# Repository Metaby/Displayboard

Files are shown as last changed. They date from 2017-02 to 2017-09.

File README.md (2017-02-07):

# Displayboard
This is the repository for my free time project. I developed the circuits to drive an DOGXL display with touchpanel from Electronic Assembly. It is driven by two Atmel microcontrollers. One ATtiny for the Touchpanel multiplexing and reading and one ATmega for driving the display itself (simple operating system, graphics driver).
The project is split into three parts
- Circuits, EAGLE files for the circuit board
- TPU, The touchpanel driver/firmware for the ATtiny
- GPU, The display driver/firmware (including a simple operating system) for the ATmega

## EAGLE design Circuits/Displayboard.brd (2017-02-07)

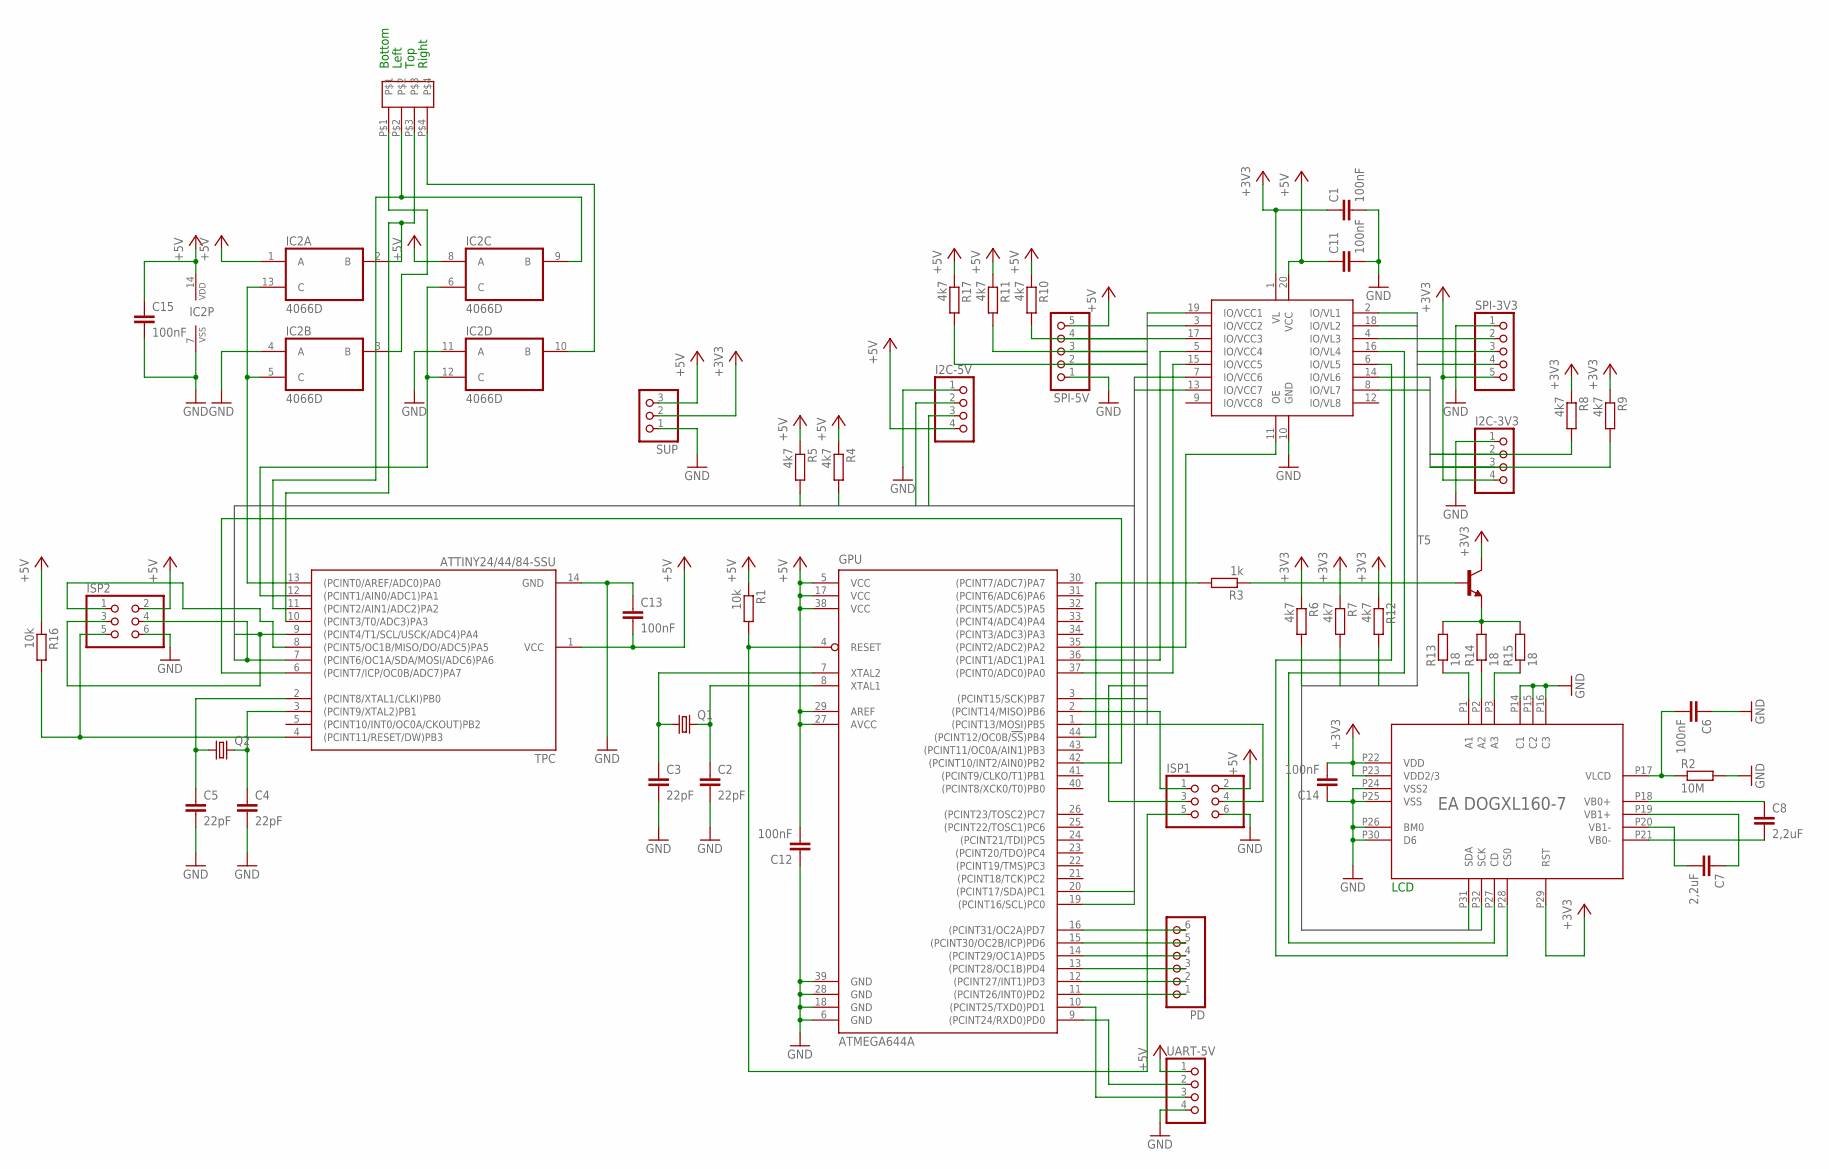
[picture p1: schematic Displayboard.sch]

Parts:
C1, C6, C11, C12, C13, C14, C15: 100nF; C1206
C2, C3, C4, C5: 22pF; C1206
C7, C8: 2,2uF; C1206
EADOGXL160-7: DOGXL
GPU: ATMEGA644A; TQFP44
I2C-3V3, I2C-5V: PINHD-1X4/90; 1X04/90
IC1: ST2378; TSSOP-20
IC2: 4066D; SO14
ISP1, ISP2: PINHD-2X3/90; 2X03/90
PD: PINHD-1X6/90; 1X06/90
Q1, Q2: CRYSTALHC49UP; HC49UP
R1, R16: 10k; R1206
R2: 10M; R1206
R3: 1k; R1206
R4, R5, R6, R7, R8, R9, R10, R11, R12, R17: 4k7; R1206
R13, R14, R15: 18; R1206
SPI-3V3, SPI-5V: PINHD-1X5/90; 1X05/90
SUP: PINHD-1X3/90; 1X03/90
T5: BCX19-NPN-SOT23-BEC; SOT23-BEC
TPC: ATTINY24/44/84-SSU; SOIC14
U$1: ZIF-4-1
UART-5V: PINHD-1X4/90; 1X04/90

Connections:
+3V3: C1.1, C14.2, EADOGXL160-7.P22 (VDD), EADOGXL160-7.P23 (VDD2/3), EADOGXL160-7.P29 (RST), I2C-3V3.4, IC1.1 (VL), R6.1, R7.1, R8.1, R9.1, R12.1, SPI-3V3.5, SUP.2, T5.C
+5V: C11.1, C12.2, C13.2, C15.1, GPU.5 (VCC), GPU.17 (VCC), GPU.27 (AVCC), GPU.29 (AREF), GPU.38 (VCC), I2C-5V.4, IC1.20 (VCC), IC2.1 (A), IC2.8 (A), IC2.14 (VDD), ISP1.2, ISP2.2, R1.1, R4.1, R5.1, R10.1, R11.1, R16.1, R17.1, SPI-5V.5, SUP.3, TPC.1 (VCC), UART-5V.1
GND: C1.2, C2.2, C3.2, C4.2, C5.2, C6.1, C11.2, C12.1, C13.1, C14.1, C15.2, EADOGXL160-7.P14 (C1), EADOGXL160-7.P15 (C2), EADOGXL160-7.P16 (C3), EADOGXL160-7.P24 (VSS2), EADOGXL160-7.P25 (VSS), EADOGXL160-7.P26 (BM0), EADOGXL160-7.P30 (D6), GPU.6 (GND), GPU.18 (GND), GPU.28 (GND), GPU.39 (GND), I2C-3V3.1, I2C-5V.1, IC1.10 (GND), IC2.4 (A), IC2.7 (VSS), IC2.11 (A), ISP1.6, ISP2.6, R2.2, SPI-3V3.1, SPI-5V.1, SUP.1, TPC.14 (GND), UART-5V.4
MISO: GPU.2 ((PCINT14/MISO)PB6), IC1.3 (IO/VCC2), ISP1.1, R10.2, SPI-5V.4
MISO3: IC1.18 (IO/VL2), R6.2, SPI-3V3.4
MOSI: GPU.1 ((PCINT13/MOSI)PB5), IC1.17 (IO/VCC3), ISP1.4, R11.2, SPI-5V.3
MOSI3: EADOGXL160-7.P31 (SDA), IC1.4 (IO/VL3), R7.2, SPI-3V3.3
unnamed: C3.1, GPU.7 (XTAL2), Q1.1
unnamed: C2.1, GPU.8 (XTAL1), Q1.2
unnamed: GPU.4 (RESET), ISP1.5, R1.2
unnamed: C5.1, Q2.1, TPC.2 ((PCINT8/XTAL1/CLKI)PB0)
unnamed: C4.1, Q2.2, TPC.3 ((PCINT9/XTAL2)PB1)
unnamed: C6.2, EADOGXL160-7.P17 (VLCD), R2.1
unnamed: IC2.2 (B), TPC.10 ((PCINT3/T0/ADC3)PA3), U$1.P$3
unnamed: C8.1, EADOGXL160-7.P18 (VB0+)
unnamed: C7.1, EADOGXL160-7.P19 (VB1+)
unnamed: C7.2, EADOGXL160-7.P20 (VB1-)
unnamed: C8.2, EADOGXL160-7.P21 (VB0-)
unnamed: GPU.36 ((PCINT1/ADC1)PA1), IC1.5 (IO/VCC4)
unnamed: IC2.9 (B), TPC.11 ((PCINT2/AIN1/ADC2)PA2), U$1.P$2
unnamed: IC2.3 (B), U$1.P$1
unnamed: GPU.16 ((PCINT31/OC2A)PD7), PD.6
unnamed: IC2.5 (C), IC2.13 (C), TPC.13 ((PCINT0/AREF/ADC0)PA0)
unnamed: IC2.6 (C), IC2.12 (C), TPC.12 ((PCINT1/AIN0/ADC1)PA1)
unnamed: IC2.10 (B), U$1.P$4
unnamed: GPU.42 ((PCINT10/INT2/AIN0)PB2), TPC.6 ((PCINT7/ICP/OC0B/ADC7)PA7)
unnamed: GPU.15 ((PCINT30/OC2B/ICP)PD6), PD.5
unnamed: GPU.14 ((PCINT29/OC1A)PD5), PD.4
unnamed: EADOGXL160-7.P27 (CD), IC1.16 (IO/VL4)
unnamed: GPU.13 ((PCINT28/OC1B)PD4), PD.3
unnamed: EADOGXL160-7.P28 (CS0), IC1.6 (IO/VL5)
unnamed: GPU.37 ((PCINT0/ADC0)PA0), IC1.15 (IO/VCC5)
unnamed: GPU.12 ((PCINT27/INT1)PD3), PD.2
unnamed: GPU.35 ((PCINT2/ADC2)PA2), IC1.11 (OE)
unnamed: GPU.11 ((PCINT26/INT0)PD2), PD.1
unnamed: GPU.10 ((PCINT25/TXD0)PD1), UART-5V.3
unnamed: GPU.9 ((PCINT24/RXD0)PD0), UART-5V.2
unnamed: R3.1, T5.B
unnamed: EADOGXL160-7.P3 (A3), R15.1
unnamed: EADOGXL160-7.P2 (A2), R14.1
unnamed: EADOGXL160-7.P1 (A1), R13.1
unnamed: R13.2, R14.2, R15.2, T5.E
unnamed: ISP2.5, R16.2, TPC.4 ((PCINT11/RESET/DW)PB3)
unnamed: GPU.44 ((PCINT12/OC0B/!SS!)PB4), R3.2
unnamed: ISP2.1, TPC.8 ((PCINT5/OC1B/MISO/DO/ADC5)PA5)
SCK: GPU.3 ((PCINT15/SCK)PB7), IC1.19 (IO/VCC1), ISP1.3, R17.2, SPI-5V.2
SCK3: EADOGXL160-7.P32 (SCK), IC1.2 (IO/VL1), R12.2, SPI-3V3.2
SCL: GPU.19 ((PCINT16/SCL)PC0), I2C-5V.2, IC1.7 (IO/VCC6), ISP2.3, R5.2, TPC.9 ((PCINT4/T1/SCL/USCK/ADC4)PA4)
SCL3: I2C-3V3.2, IC1.14 (IO/VL6), R8.2
SDA: GPU.20 ((PCINT17/SDA)PC1), I2C-5V.3, IC1.13 (IO/VCC7), ISP2.4, R4.2, TPC.7 ((PCINT6/OC1A/SDA/MOSI/ADC6)PA6)
SDA3: I2C-3V3.3, IC1.8 (IO/VL7), R9.2

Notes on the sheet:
LCD
Bottom
Left
Top
Right

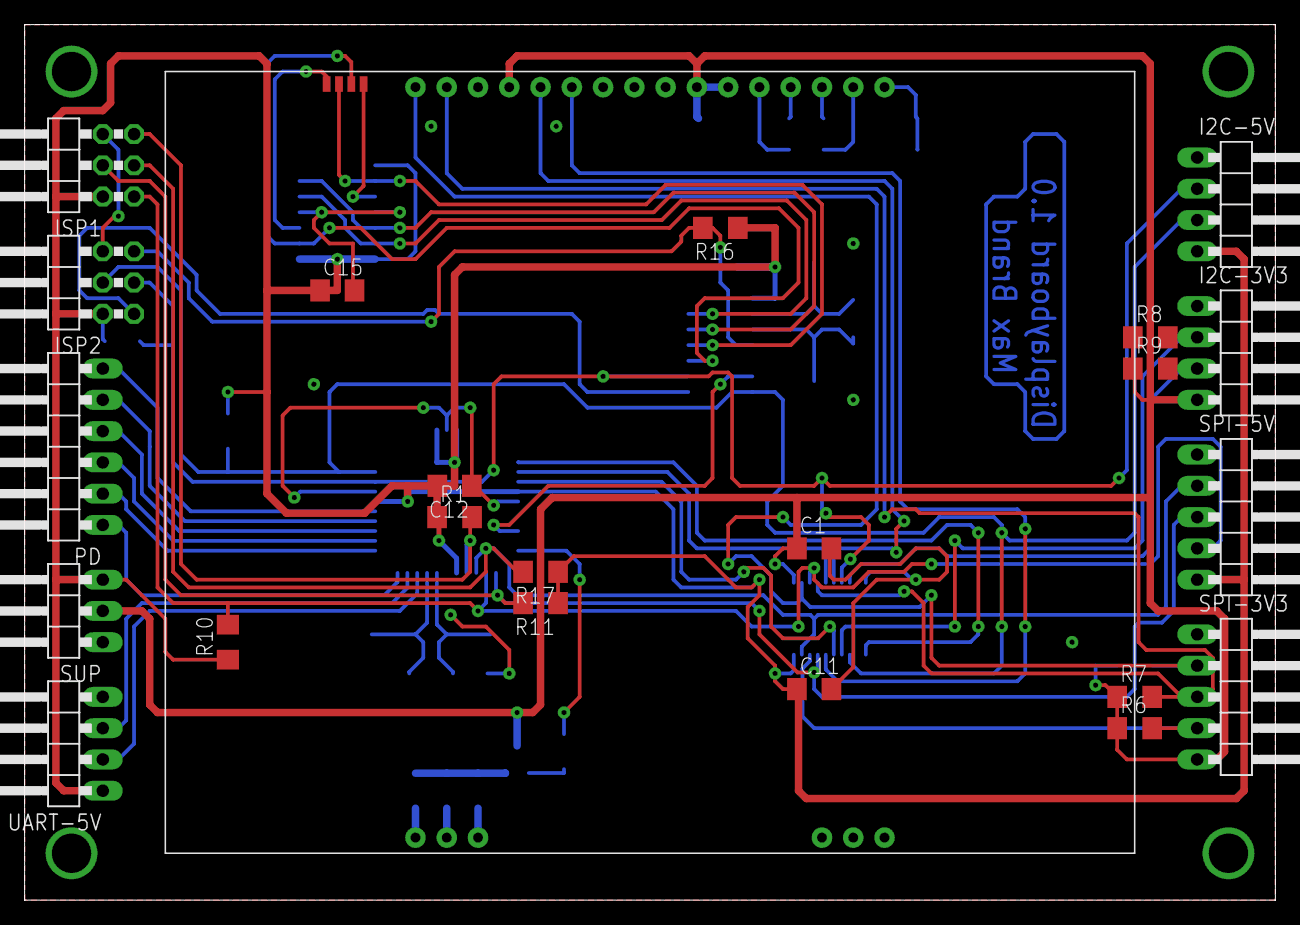
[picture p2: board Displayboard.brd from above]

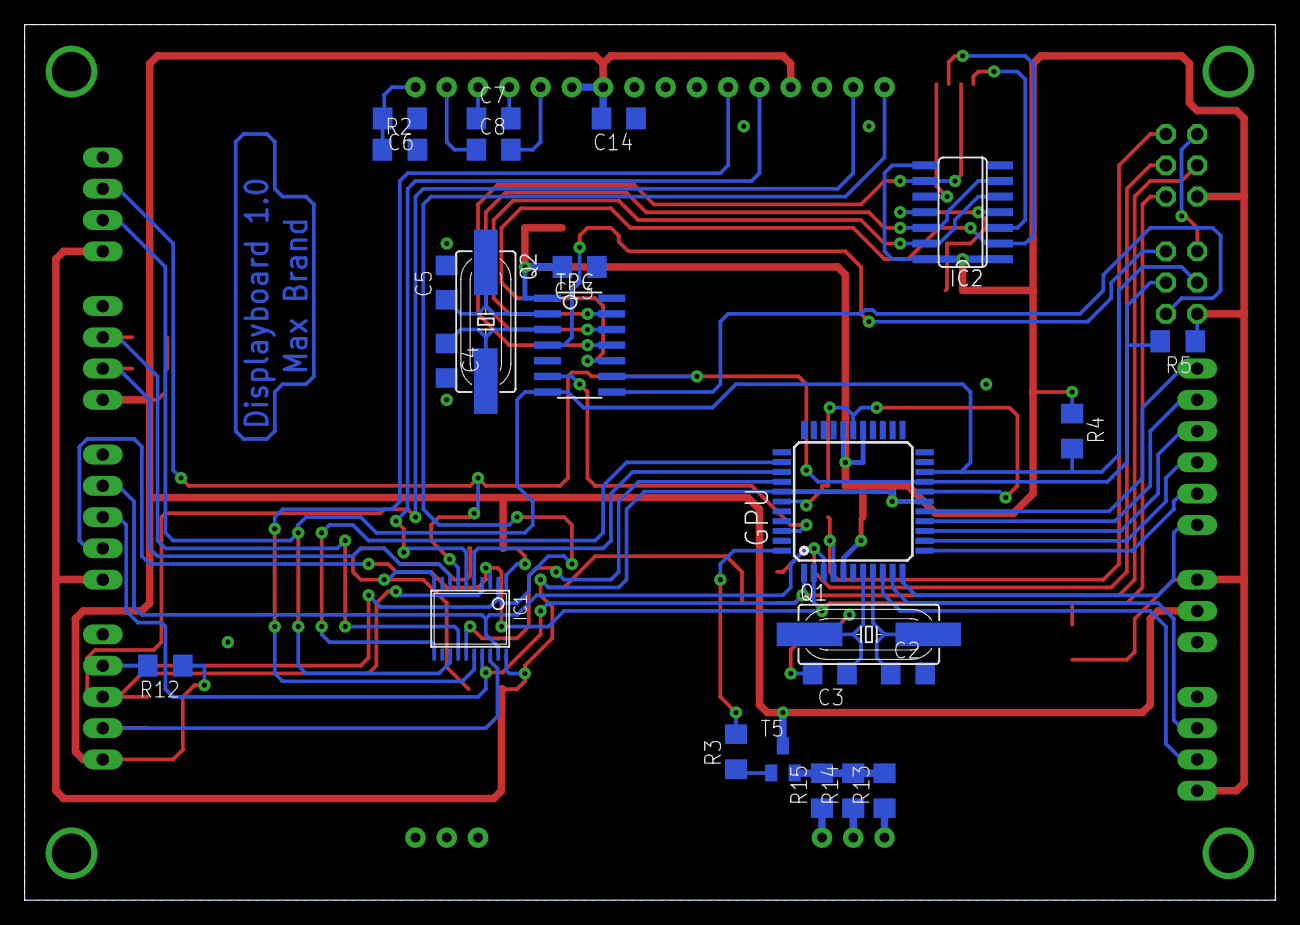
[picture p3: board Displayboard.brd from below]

Board: 2 copper layers, 101.6 x 71.1 mm, 48 parts (24 on the bottom side), 51 nets.

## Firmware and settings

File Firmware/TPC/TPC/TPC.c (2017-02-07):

/*
 * TPC.c
 *
 * Created: 09.10.2012 11:06:12
 *  Author: Max
 */
#define EnableRapidSending 0
#define F_CPU 20000000UL
#define PORTA0 0
#define PORTA1 1
#define PORTA2 2
#define PORTA3 3
#define PORTA4 4
#define PORTA5 5
#define PORTA6 6
#define PORTA7 7
#define SDA_PORT        PA6
#define SCL_PORT        PA4
#define SDA_PIN         PINA6
#define SCL_PIN         PINA4
#include <avr/io.h>
#include <util/delay.h>
#include <avr/interrupt.h>
#include "usiTwiSlave.h"

volatile uint8_t lastX = 0;
volatile uint8_t lastY = 0;

uint16_t readADC(uint8_t Channel, uint8_t Resolution)
{
	uint8_t i;
	uint32_t result = 0;
	ADCSRA = (1<<ADEN) | (1<<ADPS2) | (1<<ADPS0);
	ADMUX = Channel;
	ADCSRA |= (1<<ADSC);
	while(ADCSRA & (1<<ADSC));
	for(i=0; i < Resolution; i++) {
		ADCSRA |= (1<<ADSC);
		while(ADCSRA & (1<<ADSC));
		result += ADCW;
	}
	ADCSRA &= ~(1<<ADEN);
	result /= Resolution;
	return result;
}

void Sleep (uint16_t ms)
{
	for(; ms > 0; ms--) _delay_ms(1);
}

uint8_t SampleY()
{
	DDRA |= (1 << PORTA1) | (1 << PORTA0);
	PORTA |= (1 << PORTA0) | (1 << PORTA3);
	PORTA &= ~(1 << PORTA1);
	uint16_t minY = 400;//360;
	uint16_t maxY = 815;//815;
	return (uint8_t)((readADC(2, 10) - minY) * (104.0 / (maxY - minY)));
}

uint8_t SampleX()
{
	DDRA |= (1 << PORTA1);
	PORTA |= (1 << PORTA1) | (1 << PORTA2);
	PORTA &= ~(1 << PORTA0);
	uint16_t minX = 215;//175;
	uint16_t maxX = 830;//830;
	return (uint8_t)((readADC(3, 10) - minX) * (160.0 / (maxX - minX)));
}

void Initialize()
{
	usiTwiSlaveInit(0x0C);
	TCCR1B = (1 << CS11);
	TIMSK1 = (1 << TOIE1);
	TCNT1H = 0xAF;
	TCNT1L = 0xFF;
	Sleep(1000);
	sei();
}

int main(void)
{
	Initialize();
    while(1);
}

ISR(TIM1_OVF_vect)
{
	TIMSK1 = 0x00;
	TCNT1H = 0xAF;
	TCNT1L = 0xFF;
	uint8_t x = 160 - SampleX();
	uint8_t y = 104 - SampleY();
	uint8_t send = 0;
	if (lastX != x)
	{
		lastX = x;
		send = 1;
	}		
	if (lastY != y)
	{
		lastY = y;
		send = 1;
	}		
	txbuffer[0] = lastX;
	txbuffer[1] = lastY;
	if (send == 1 || EnableRapidSending)
	{
		DDRA |= (1 << PORTA7);
		PORTA &= ~(1 << PORTA7);
		PORTA |= (1 << PORTA7);
	}
	TIMSK1 = (1 << TOIE1);
}

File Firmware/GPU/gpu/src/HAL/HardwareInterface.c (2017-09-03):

/*
 * HardwareInterface.c
 *
 * Created: 23.11.2012 20:54:42
 *  Author: Max
 */
#include "HardwareInterface.h"

void display_initialize()
{
	DDRA = (1 << PORTA0) | (1 << PORTA1) | (1 << PORTA4);
	DDRB = (1 << PORTB4) | (1 << PORTB5) | (1 << PORTB7);
	SPCR = (1 << SPE) | (1 << MSTR);
	SPSR = (1 << SPI2X);
	display_enable(0);
	display_send_byte(0xF1);
	display_send_byte(0x67);
	display_send_byte(0xC0);
	display_send_byte(0x40);
	display_send_byte(0x50);
	display_send_byte(0x2B);
	display_send_byte(0xEB);
	display_send_byte(0x81);
	display_send_byte(0x69);
	display_send_byte(0x89);
	display_send_byte(0xAF);
	display_send_byte(0xA4);
}

void display_send_byte(uint8_t Data)
{
	SPDR = Data;
	while(!(SPSR & (1 << SPIF)));
}

void display_enable(uint8_t CD)
{
	PORTA = (0 << PORTA0) | (CD << PORTA1);
}

void display_disable()
{
	PORTA = (1 << PORTA0);
}

void display_select_column(uint8_t Column)
{
	display_enable(0);
	display_send_byte(0x0 | (Column & 0x0F));
	Column = (Column >> 4);
	display_send_byte(0x10 | (Column & 0x0F));
}

void display_select_page(uint8_t Page)
{
	display_enable(0);
	display_send_byte(0x60 | (Page & 0x1F));
}

void display_clear()
{
	display_select_column(0);
	display_select_page(0);
	display_enable(1);
	for (uint8_t i = 0; i < 200; i++)
	{
		for (uint8_t j = 0; j < 32; j++)
		{
			display_send_byte(0x00);
		}
	}
}

void display_send_buffer()
{
	display_select_column(0);
	display_select_page(0);
	display_enable(1);
	for (uint8_t y = 0; y < 26; y++)
	{
		if (display_row_flag[y] == 1)
		{
			for (uint8_t x = 0; x < 160; x++)
			{
				display_send_byte(display_buffer[x][y]);
			}
			display_row_flag[y] = 0;
		}
		else
		{
			display_enable(0);
			display_select_page(y + 1);
			display_enable(1);
		}
	}
}

void display_get_touch()
{	
	i2c_start_wait(0x0C + TW_WRITE);
	i2c_write(0x00);
	i2c_stop();
	i2c_start_wait(0x0C + TW_READ);
	touch_position.x = i2c_readAck();
	touch_position.y = i2c_readNak();
	i2c_stop();
}

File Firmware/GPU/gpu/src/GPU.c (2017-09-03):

/*
 * Displayboard_Funktionstest.c
 *
 * Created: 09.10.2012 00:08:43
 *  Author: Max
 */ 
#include "GPU.h"

int main(void)
{
	hardware_initialize();
	disp_driver_initialize();
	kernel_initialize();
	kernel_run();
}

void hardware_initialize()
{
	// Draw-Timer
	TCCR1B = (1 << CS01);
	TIMSK1 = (1 << TOIE1);
	TCNT1H = 0xF6;
	TCNT1L = 0x3B;
	// 1s Timer
	TCCR3B = (1 << CS30) | (1 << CS32);
	//	TIMSK3 = (1 << TOIE3);
	// 	TCNT3H = 0xEA;//E2;
	// 	TCNT3L = 0x60;//B3;
	// Touch-Interrupt
	EICRA = 0x10;
	EIMSK = 0x04;
	EIFR = 0x04;
	// Brightness-PWM-Timer
	TCCR0A = (1 << WGM00) | (1 << WGM01) | (1 << WGM02) | (1 << COM0B1);
	TCCR0B = (1 << CS02) | (1 << CS00);
	OCR0B = brightness_table[brightness];
	// UART
	DDRD = (1 << PORTD0);
	UBRR0 = 0x81;
	UCSR0B = (1 << RXEN0) | (1 << TXEN0);
	//UCSR0B = (1 << RXCIE0) | (1 << RXEN0) | (1 << TXEN0);
	UCSR0C = (1 << UCSZ01) | (1 << UCSZ00);
	// i2c
	i2c_init();
	sei();
}

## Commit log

2017-02-07 Init
    Initial commit of existing project.
    [Displayboard.brd, Displayboard.sch]
2017-04-09 Fixed bugs and improved the kernel
    + Print numbers bug fixed
    + listening on rs232 port is now a kernel program
    + created operating_system program, not finished
    [GPU.c]
2017-04-09 Improvements and bug fixes on operating system and kernel
    + Added touch_function for programs
    // Interrupt problem on dev board, need to fix this first
    [GPU.c]
2017-09-03 Bugfixes, Font improvment
    + Fixed some bugs that broke the touch function.
    + Removed the operating system function and improved the kernel. The kernel now runs the operating system directly.
    + Remade the font for better readability.
    [GPU.c, HardwareInterface.c]
